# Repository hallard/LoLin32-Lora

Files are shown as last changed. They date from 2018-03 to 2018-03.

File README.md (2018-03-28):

# ESP32 LoLin32 Lora Shield for RFM95 or RN2483
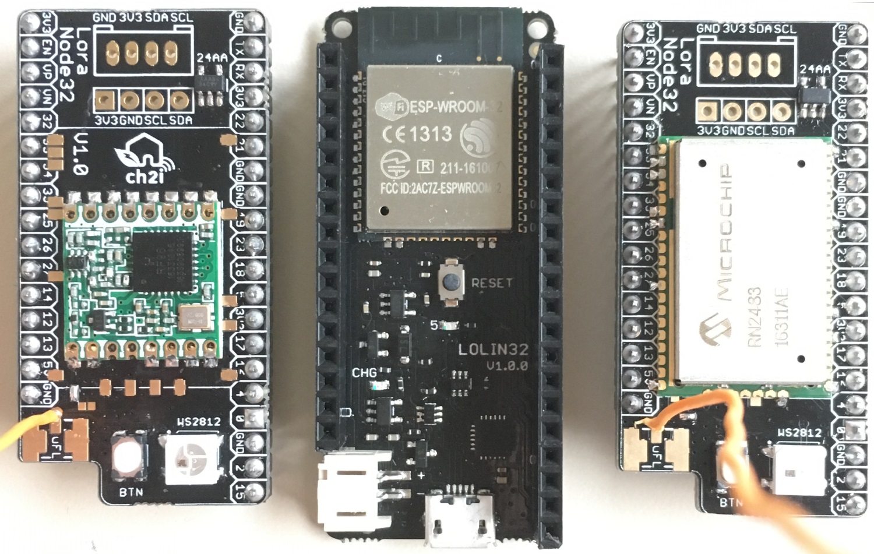
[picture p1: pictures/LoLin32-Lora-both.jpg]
LoraNode32 in 2 versions with LoLin32


This shield is used to hold LoRa modules such as HopeRF [RFM95][4] or Mictrochip [RN2483][7] with WeMos ESP32 [LoLin32][20] boards it has the followong features:
- I2C Pullups placement
- Classic I2C connector with SCL/SDA and 3V3/GND reversable pin by solder pad
- Groove I2C connector
- Footprint for RFM95/96/98 or RN2483/RN2903 Lora module
- Footprint for choosing single Wire, SMA or u-FL Antenna type 
- 1 x WS2812B Type LED for visual indication
- 1 x Push Button
- Added footprint for Microchip 24AA02E64 64 bits serial number (DEVEUI)

**Take care that WeMos changed Lolin32 format**, you need to choose V1.0.0 that you can find on ebay, [banggood][10] or aliexpress. ~~Wemos does net seem to produce this board anymore~~. They're Back [here][11]. They do now Provide WeMos [Lolin32 Pro][21] or [Lolin32 Lite][22]

**So be sure to order board in the center of the picture above**

You can also check the shield for the [Lolin32 Lite][9] version. 

# Detailed Description

Look at the schematics for more informations.

SPI connexion is classic (MOSI/MISO/CLK), 

Other pins that may need be adapted into code (for example if you use TTN network gateway code) according to the following pinout

```
Lolin32      RFM9x Module
  IO5   <----> SEL 
  IO19  <----> MISO
  IO23  <----> MOSI
  IO18  <----> CLK
  IO27  <----> DIO0
  IO26  <----> DIO1
  IO4   <----> DIO2
  IO25  <----> RST
  IO35  <----> DIO5

Lolin32      RN2xx3 Module
  IO4   <----> RESET
  IO25  <----> RX
  IO35  <----> TX

Lolin32      Shield Feature
  IO22  <----> I2C SCL
  IO21  <----> I2C SDA
  IO13  <----> WS2812 LEDS
  IO15  <----> Push Button
```

**Do not forget to join (solder) the correct LoRa antenna trace** depending on module you place (RFM95 or RN2483), see picture below.

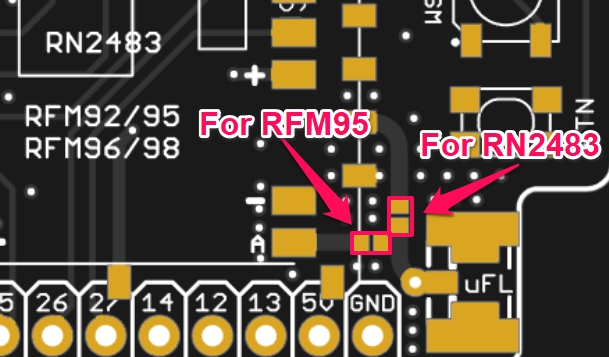
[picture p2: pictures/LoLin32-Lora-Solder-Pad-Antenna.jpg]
Antenna Solder Pad


And as classic advice, **connect the LoRa antenna before powering** the board to avoid any damage to LoRa module

# Schematic  

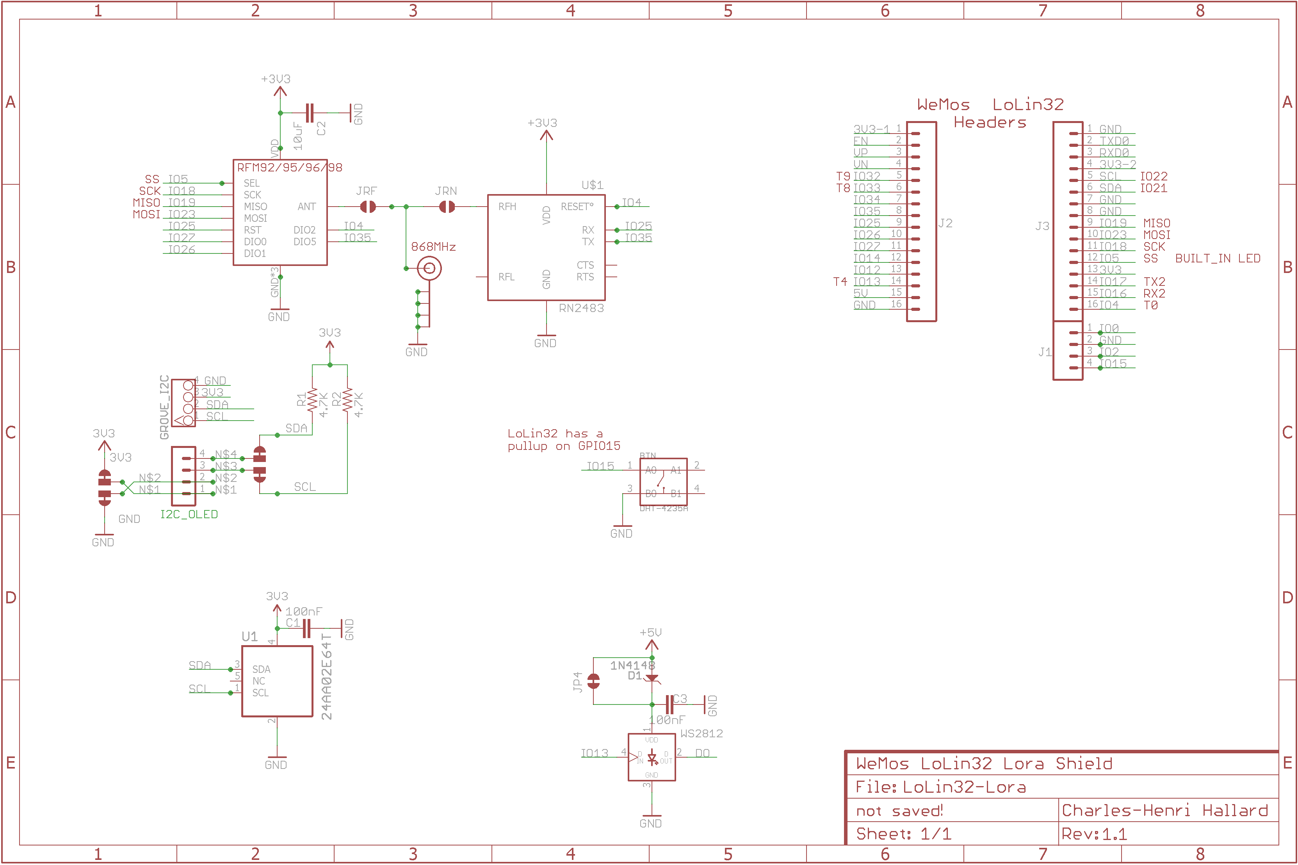
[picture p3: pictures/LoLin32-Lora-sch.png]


# Firmware  

There is no firmware available, but you can have a large demo of features and a full working LoRa node (with RFM95) with this excellent [ESP32-Paxcounter](https://github.com/cyberman54/ESP32-Paxcounter/) software, it's a must see.

# Boards  

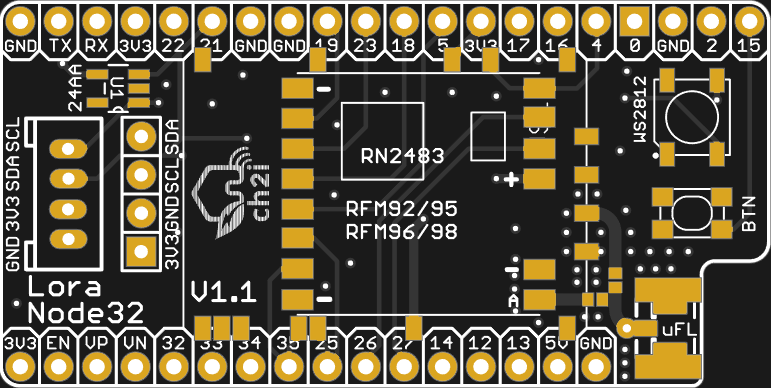
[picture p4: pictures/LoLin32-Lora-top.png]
Top
&nbsp;
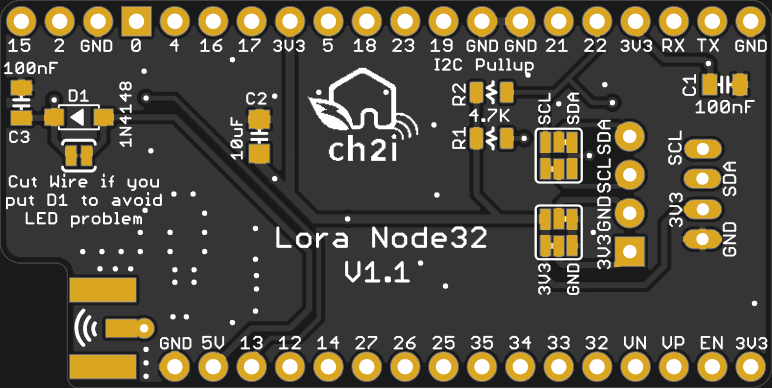
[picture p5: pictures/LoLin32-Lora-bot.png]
Bottom


You can order the PCB of this board at [PCBs.io][3]. PCBs.io give me some reward when you order my designed boards from their site. This is pretty good, because I can use these rewards to create and design new boards and order them for free, so if you don't care about PCB manufacturer please use PCBs.io.

# Assembled boards (V1.0)

## With RFM95

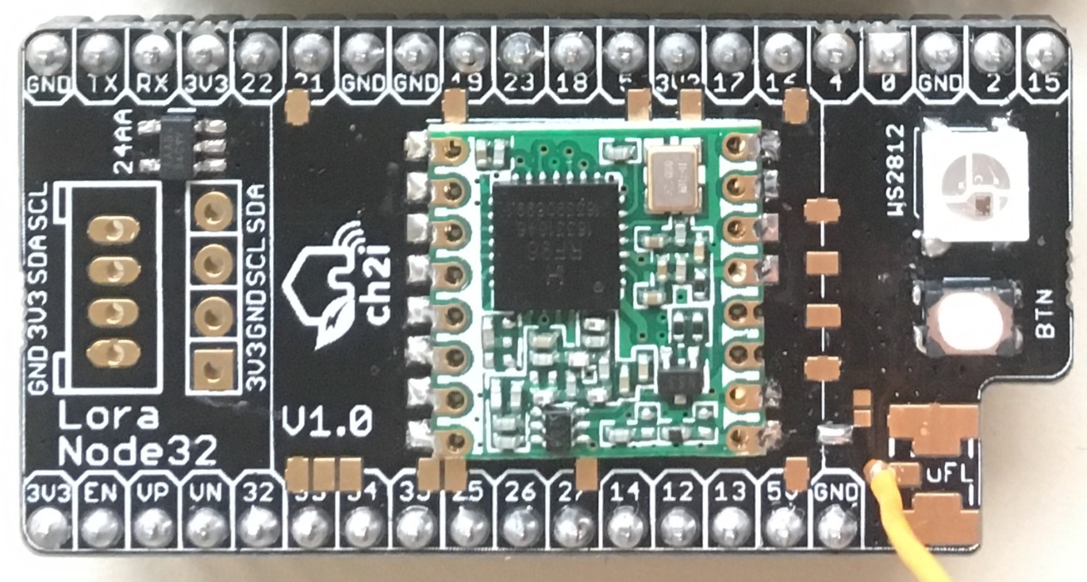
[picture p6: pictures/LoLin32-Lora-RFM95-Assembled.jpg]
LoraNode32 with RFM95


## With RN2483

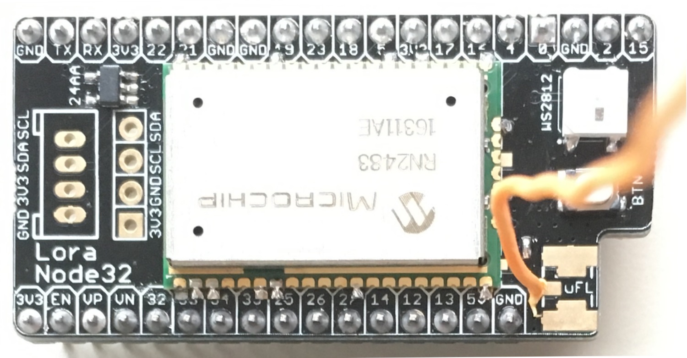
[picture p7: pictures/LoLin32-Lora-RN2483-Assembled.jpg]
LoraNode32 with RN2483


# License

   

This work is licensed under a [Creative Commons Attribution-NonCommercial 4.0 International License](http://creativecommons.org/licenses/by-nc/4.0/)    
If you want to do commercial stuff with this project, please contact [CH2i company](https://ch2i.eu/en#support) so we can organize an simple agreement.

# Misc

See news and other projects on my [blog][2] 
 
[2]: https://hallard.me
[3]: https://PCBs.io/share/zO3Ye
[4]: http://www.hoperf.com/rf_transceiver/lora/
[5]: https://github.com/hallard/ESP-1ch-Gateway/
[6]: https://github.com/matthijskooijman/arduino-lmic/pull/34
[7]: https://www.microchip.com/wwwproducts/en/RN2483
[9]: https://github.com/hallard/LoLin32-Lite-Lora

[10]: http://www.banggood.com/WeMos-LOLIN32-V1_0_0-WiFi-Bluetooth-Board-Based-ESP-32-4MB-FLASH-p-1164252.html
[11]: https://www.aliexpress.com/store/product/WEMOS-LOLIN32-V1-0-0-wifi-bluetooth-board-based-ESP-32-4MB-FLASH/1331105_32808551116.html

[20]: https://wiki.wemos.cc/products:lolin32:lolin32
[21]: https://wiki.wemos.cc/products:lolin32:lolin32_pro
[22]: https://wiki.wemos.cc/products:lolin32:lolin32_lite

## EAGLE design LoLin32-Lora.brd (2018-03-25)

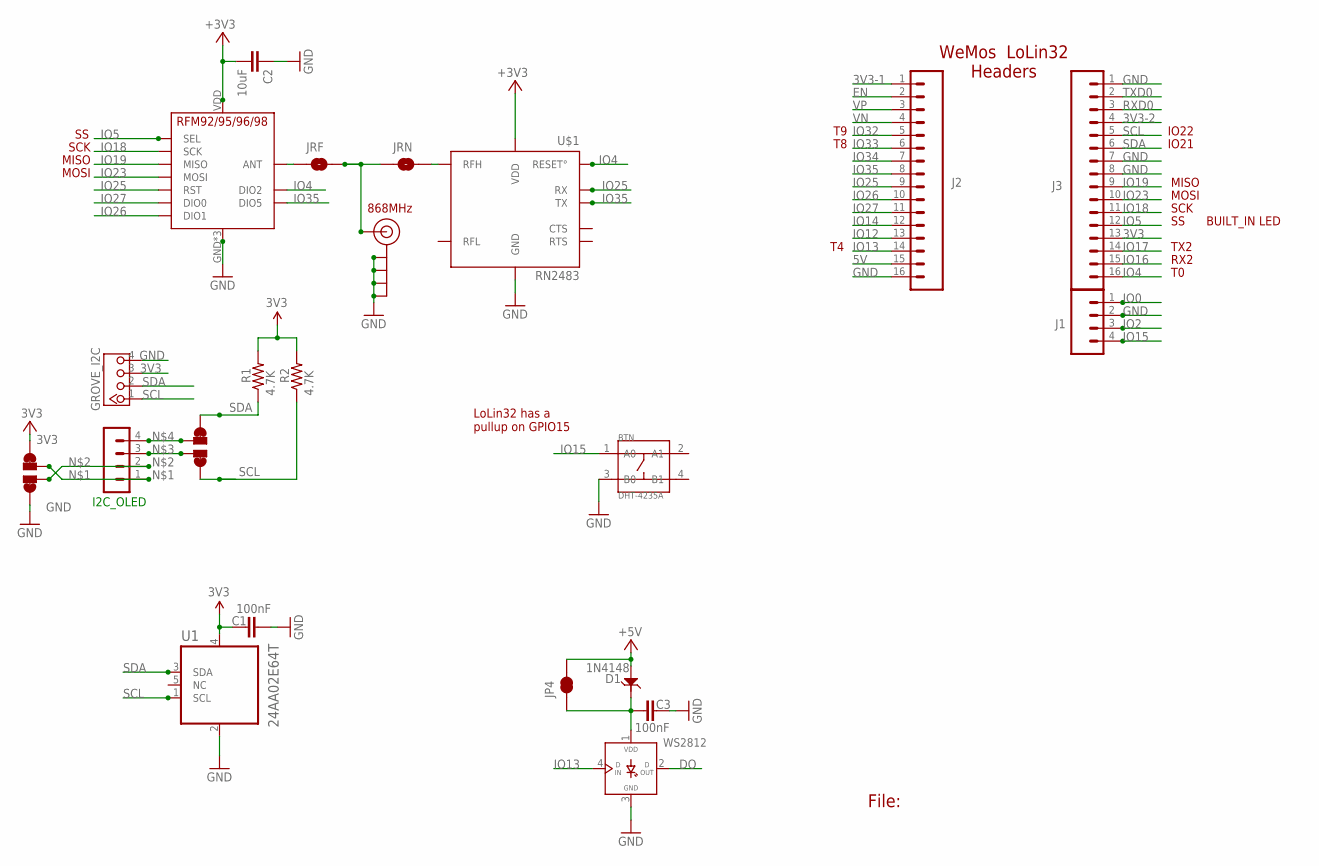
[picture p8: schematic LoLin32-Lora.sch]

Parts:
BTN: DHT-4235A; SW4-SMD-4.2X3.2X2.5MM
C1, C3: 100nF; 0805-CAP
C2: 10uF; 0805-CAP-LARGEPADS
D1: 1N4148; SOD123-2.7X1.6
GROVE_I2C: 4P-2.0; HW4-2.0
I2C_OLED: CON_HEADER_1X04'NO_LOCK'; 1X04_NO_LOCK
J1: M041X04_NO_SILK; 1X04_NO_SILK
J2, J3: M161X16_NO_SILK; 1X16_NO_SILK
J$2: ANTENNATINY; SMA_UFL_PAD_TINY
JP4: JUMPER-PAD-2-NC_BY_TRACE; PAD-JUMPER-2-NC_BY_TRACE_YES_SILK
JRF: JUMPER-PAD-2-NO; PAD-JUMPER-2-NO_NO_SILK
JRN: JUMPER-PAD-2-NO; PAD-JUMPER-2-NO_NO_SILK
R1, R2: 4.7K; 0805-RES
U1: 24AA02E64T; SOT95P270X145-5N
U$1: RN2483; RN2483_NOGPIO_868
U$2, U$3: PAD-JUMPER-SWAPSWAP; PAD-JUMPER-SWAP
U$5: RFM95
WS2812: WS2812B

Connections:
3V3: C2.2, GROVE_I2C.3, J3.13, R1.2, R2.2, U$1.VDD, U$1.VDD2 (VDD), U$2.4, U$2.44 (4), U$5.VDD (VCC)
3V3-1: J2.1
3V3-2: C1.1, J3.4, U1.4 (VCC)
5V: D1.1, J2.15, JP4.2
DO: WS2812.2 (DOUT)
EN: J2.2
GND: BTN.3 (B0), C1.2, C2.1, C3.2, GROVE_I2C.4, J1.2, J2.16, J3.1, J3.7, J3.8, J$2.GND1 (GND), J$2.GND2 (GND), J$2.GND3 (GND), J$2.GND4 (GND), U1.2 (VSS), U$1.GND, U$1.GND3 (GND), U$1.GND4 (GND), U$1.GND7 (GND), U$1.GND9 (GND), U$1.GND11 (GND), U$1.GND12 (GND), U$2.1, U$2.11 (1), U$5.GND, U$5.GND1 (GND), U$5.GND2 (GND), WS2812.3 (GND)
IO0: J1.1
IO2: J1.3
IO4: J3.16, U$1.RESET°, U$5.DIO2
IO5: J3.12, U$5.NSS (SEL)
IO12: J2.13
IO13: J2.14, WS2812.4 (DIN)
IO14: J2.12
IO15: BTN.1 (A0), J1.4
IO16: J3.15
IO17: J3.14
IO18: J3.11, U$5.SCK
IO19: J3.9, U$5.MISO
IO23: J3.10, U$5.MOSI
IO25: J2.9, U$1.UART_RX (RX), U$5.RST
IO26: J2.10, U$5.DIO1
IO27: J2.11, U$5.DIO0
IO32: J2.5
IO33: J2.6
IO34: J2.7
IO35: J2.8, U$1.UART_TX (TX), U$5.DIO5
unnamed: I2C_OLED.1, U$2.3
unnamed: I2C_OLED.2, U$2.2
unnamed: I2C_OLED.3, U$3.2
unnamed: I2C_OLED.4, U$3.3
unnamed: JRN.2, U$1.RFH
unnamed: JRF.1, U$5.ANT
unnamed: J$2.ANT1 (SIGNAL), J$2.ANT2 (SIGNAL), J$2.ANT3 (SIGNAL), JRF.2, JRN.1
RXD0: J3.3
SCL: GROVE_I2C.1, J3.5, R2.1, U1.1 (SCL), U$3.1, U$3.11 (1)
SDA: GROVE_I2C.2, J3.6, R1.1, U1.3 (SDA), U$3.4, U$3.44 (4)
TXD0: J3.2
VLED: C3.1, D1.2, JP4.1, WS2812.1 (VDD)
VN: J2.4
VP: J2.3

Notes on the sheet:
File:
WeMos LoLin32 Headers
868MHz
MOSI
MISO
SCK
LoLin32 has a pullup on GPIO15
IO21
IO22
RX2
TX2
BUILT_IN LED

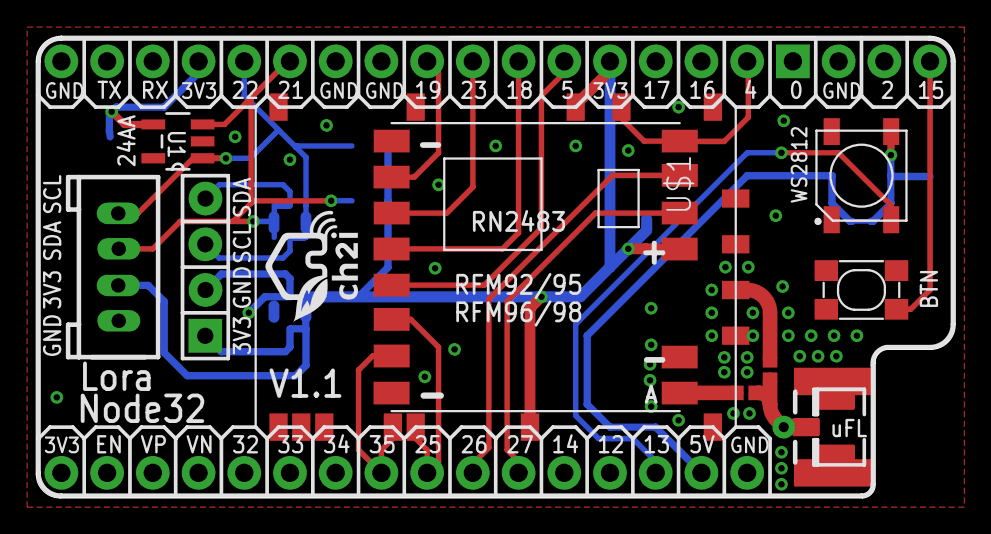
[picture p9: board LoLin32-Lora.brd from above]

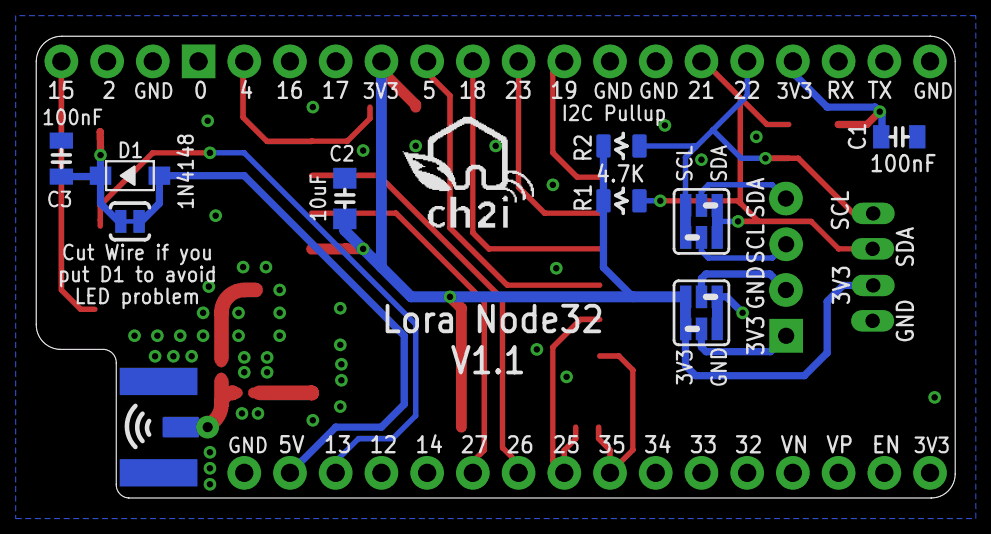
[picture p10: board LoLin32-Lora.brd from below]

Board: 2 copper layers, 51.1 x 25.7 mm, 24 parts (10 on the bottom side), 25 nets.

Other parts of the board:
U$4: LOGO_CH2I_75MM
U$6: LOGO_C2I_015

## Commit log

2018-03-25 Bump to V1.1
    [LoLin32-Lora.brd, LoLin32-Lora.sch]
2018-03-26 Added board warning
2018-03-26 Added doc on LoRa antenna solder pad

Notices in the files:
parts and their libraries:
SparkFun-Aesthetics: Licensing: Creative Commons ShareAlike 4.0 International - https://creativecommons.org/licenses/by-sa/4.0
